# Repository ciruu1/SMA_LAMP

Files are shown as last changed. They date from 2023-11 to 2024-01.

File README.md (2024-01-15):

# SMA_LAMP

This repository contains the source code, hardware design, and documentation for an embedded systems project.

## Directory Structure

### 1. DOCS

- **Description:** This directory holds documentation related to the project.

  - **SysML:** This subdirectory contains System Modeling Language (SysML) diagrams and documentation describing the system architecture and design.

### 2. HW

- **Description:** The hardware-related files and designs are stored in this directory.

  - **SE_ejemplo:** This subdirectory includes hardware design files and documentation for the KiCad design related to the embedded systems project.

### 3. SW

- **Description:** The software source code for the embedded systems project is organized within this directory.

  - **SMA_LAMP.X:** This subdirectory holds the source code for the main module related to lamp control (MPLAB X project).

  - **Terminal:** This subdirectory contains the source code for the terminal module, which may be responsible for user interface and interaction.

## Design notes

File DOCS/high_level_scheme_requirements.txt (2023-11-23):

EM(estructura mecánica)[1]
CA(Circuito de acondicionamiento)[1]
↑
Interfaz HW(Pines)[1]
↓
SMA_LAMP(Sistema de monitorización y actuación):
    - Encendido:
        · leer_configuracion()
        · avisar_SMA_COMP()
    - Apagado:
        · guardar_configuración()
        · avisar_SMA_COMP()
    - Monitorización:
        · recibir_comandos_pc()
        · leer_sensores():
            # Ruido
            # CO2
            # Temperatura
            # Humedad
            # Luminosidad
    - Actuación:
        · enviar_info_pc()
        · modificar_velocidad()
        · modificar_LEDs()

↕
Interfaz_PC(USART)
↕
SMA_COMP(LINUX):
    - SW:
        · enviar_comandos() {cambiar_luz, cambiar_iluminación, modificar_velocidad}
        · mostrar_estado_variables() {Ruido, CO2, Humedad, Temperatura, Luminosidad} [2]
        · comprobar_estado_SMA_LAMP()

[1]: Nos viene ya hecho, no tenemos que desarrollar nada
[2]: Se muestra el estado de los sensores, aquellos que no estén disponibles también aparecerá el estado: NO DISPONIBLE TODAVÍA(De acuerdo con el requisito ENC-20)

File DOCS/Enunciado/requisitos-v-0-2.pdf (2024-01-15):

# Requisitos para lámpara de mesa diseñada para el estudio Sección: Sistema de monitorización y actuación

# LMDE-MA v-0.2

Norberto Cañas

## 1. Introducción

### 1.1. Propósito

Este documento establece un punto de partida, relativamente preciso, para el desarrollo del primer prototipo de un sistema empotrado (SE) para una lámpara de mesa diseñada para el estudio (LMDE). El dispositivo tiene funciones añadidas de monitorización del ambiente cercano, así como funciones de ajuste de la iluminación suministrada y velocidad de giro de un ventilador acoplado a la base del dispositivo.

### 1.2. Alcance

El prototipo a desarrollar se ha dividido en tres componentes.

Estructura mecánica (EM) Suministra los soportes necesarios para alojar el resto de componentes.

Circuito de acondicionamiento (CA) Realiza actividades de acondicionamiento de señal para sensores y actuadores.

Sistema de monitorización y actuación (SMA) Realiza la monitorización de algunas variables ambientales de interés en actividades de estudio, así como suministra la posibilidad de actuar sobre la velocidad de giro de un ventilador, ajustar el color de la luz emitida por la lámpara y la iluminancia de la misma.

Los componentes EM y CA ya disponen de un primer prototipo completamente construido. El presente documento describe qué debe hacer el componente SMA.

1

## 2. Descripción general

### 2.1. Visión general del documento

Se describen a continuación los detalles del sistema que debe construirse.

Este apartado está estructurado de la siguiente forma:

Perspectiva del producto.
Interfaces hardware existentes
Funciones del sistema.
Restricciones.

En el capítulo siguiente (3) se detallan los requisitos específicos.

### 2.2. Perspectiva del producto

El componente SMA debe interactuar con el componente CA, respetando el interfaz de este último. El componente SMA también debe interactuar con un computador personal, en el que realmente se despliega el interfaz que se ofrece al usuario final.

### 2.3. Interfaces hardware existentes

### 2.3.1. Interfaz del componente CA

El componente CA ofrece un interfaz hardware con un conector de pines (cuadrado de 0.64mm de lado, con separación 2.54 mm entre centros) que permite acceder a las siguientes señales (ordenadas según el número de pin), interpretando el sentido de la información según el punto de vista del componente SMA:

1. Nivel de ruido. Señal de entrada analógica que codifica el nivel de ruido en el ambiente circundante.
2. SCL. Línea de sincronización para dispositivos conectados a un bus I2C.
3. SDA. Línea de datos para dispositivos conectados a un bus I2C (el componente SMA actúa como maestro del bus I2C).
4. Humedad relativa. Señal de entrada analógica que codifica la humedad relativa del ambiente circundante.
5. Temperatura. Señal de entrada analógica que codifica la temperatura del ambiente circundante.
6. PWM ventilador. Señal de salida que comanda, con su ciclo de trabajo, el nivel de alimentación del motor DC de un ventilador.
7. SCK (Serial Clock). Línea de reloj de un bus SPI.
8. SDO (Serial Data Out). Linea de salida de datos hacia un bus SPI.

2

El nivel de ruido es una señal analógica cuyos detalles de interpretación se detallan en el apartado de requisitos específicos.

El bus I2C conecta el sensor de luminosidad y el sensor de CO2, y debe funcionar a la velocidad estándard de 100 KHz.

El bus SPI conecta una tira de leds (de adafruit), constituida por leds SK9822.

Los sensores de temperatura y humedad relativa suministran señales analógicas.

Los sensores usilizados (salvo el sensor de nivel de ruido) son los siguientes y deben consultarse sus respectivas hojas técnicas (que acompañan a este documento) para entender como interactuar con ellos.

Sensor de luminosidad VEML7700

Sensor de CO2 iAQ-Core

Sensor de humedad relativa HIH4000

Sensor de temperatura LM35-LP

### 2.3.2. Interfaz computador personal

Para ganar en flexibilidad se ha decidido que el interfaz de monitorización y ajuste de la unidad LMDE, que se ofrezca al usuario final, se despliegue en un computador personal ubicado en la misma mesa de estudio que la lámpara.

El SMA deberá ofrecer un interfaz UART para conectarse con el computador personal, el cual ofrecerá un interfaz USB. Para ello se utilizará el conversor TTL-232R-RPi (FTDI).

### 2.3.3. Interfaz de usuario

El interfaz de usuario debe desarrollarse para una máquina LINUX. A nivel de prototipo existen actualmente los servicios que permiten operar el sistema en linea de comandos (aunque no se respetan todos los requisitos del sistema). Sin embargo, el interfaz definitivo debería ser un interfaz de ventanas.

En cualquier caso, el sistema debe mostrar en pantalla el estado de las variables ambientales (nivel de ruido, nivel de CO2, humedad relativa, temperatura y luminosidad), al tiempo que debe permitir cambiar el color de la luz emitida y el nivel de iluminación, así como la velocidad del ventilador.

Detalles más concretos se indican en el apartado de requisitos específicos.

### 2.4. Funciones del sistema

Las funciones del sistema son fundamentalmente dos:

3

Monitorización El sistema debe monitorizar una serie de parámetros ambientales que tienen interés para determinar si el ambiente de estudio es adecuado. Fundamentalmente son: Nivel de ruido ambiente, nivel de CO2, nivel de temperatura, nivel de humedad relativa, nivel de luminosidad.

Ajuste del comportamiento El sistema debe permitir ajustar el color de la luz emitida de la lámpara, la iluminancia de la luz emitida y la velocidad de rotación de un ventilador sujeto al soporte de la lámpara.

### 2.5. Restricciones

1. Por la configuración seleccionada para el interfaz de usuario, el componente SMA se dividirá en dos subcomponentes.

SMA-LAMP Estará constituido por el el hardware y software ubicado en la lámpara destinado a recibir la información de los sensores, tratar dicha información y enviarla al computador de sobremesa. Del mismo modo atenderá los comandos que lleguen desde el computador de sobremesa para actualizar el comportamiento de los leds así como el del ventilador.

SMA-COMP Será un componente software desplegado en el computador de sobremesa, que ofrecerá el interfaz de la lámpara con el usurio.

2. Por condicionantes externos, el microcontrolador a utilizar en el componente SMA-LAMP debe ser el PIC16F886.
3. Las dimensiones de la placa del componente SMA no pueden ser superiores a 6 cm x 6 cm.
4. Es necesario reservar espacio en la placa para cuatro tornillos de sujeción, de 4mm de diámetro, cerca de las esquinas de la misma. El margen necesario debe ser de 5mm de diámetro para poder alojar la cabeza de los tornillos.

## 3. Requisitos específicos

Encendido del sistema Este caso de actividad contempla las acciones que deben realizarse al encender el sistema.

ENC-10 Por defecto, se arrancará en primer lugar SMA-LAMP, alimentando la lámpara, para a continuación arrancar SMA-COMP, en el computador de sobremesa.

ENC-20 En el momento de arrancar se ofrecerá la información de los sensores disponibles y se indicará el estado de aquellos que requieran un proceso arranque más prolongado.

ENC-30 La lámpara debe arrancar respetando la última configuración utilizada en lo referente a leds y ventiladores. En el caso de ser la primera vez que se enciende se optará por una opción intermedia de luz blanca y ventilador apagado.

Apagado del sistema Este caso de actividad contempla las acciones que deben realizarse ante los diferentes escenarios de apagado del sistema.

AP-10 Si se apaga el sistema SMA-COMP, el sistema SMA-LAMP debe seguir funcionando con normalidad según la última configuracion establecida.

4

AP-20 Si se apaga SMA-LAMP, SMA-COMP debe indicar que SMA-LAMP se ha desconectado. En este caso, SMA-COMP no debe volver a operar hasta despues de que la aplicación se haya reinicializado.
AP-30 SMA-COMP debe ofrecer alguna alternativa para apagar la aplicación.

Monitorización de variables ambientales Este caso de actividad contempla las acciones que deben realizarse en relación con la monitorización de variables ambientalers.

MO-10 El nivel de ruido es una señal en voltaje. Deben considerarse las siguientes categorías para el ruido:
Ruido bajo La lectura del convertidor analógico digital está en el intervalo [0,400].
Ruido intermedio La lectura del convertidor analógico digital está en el intervalor [401, 900].
Ruido alto La lectura del convertidor analógico digital está por encima de 900.

MO-20 El nivel de ruido debe monitorizarse cada 10 ms, pero en el interfaz humano solo debe mostrarse la catergoría de ruido más alta alcanzada cada segundo.

MO-30 El nivel de CO2, humedad relativa, temperatura y la iluminancia, deben ser muestreados cada 5 segundos y actualizarse en pantalla con el mismo periodo.
MO-40 La unidades a utilizar para las magnitudes muestreadas (salvo el ruido, que ya ha sido categorizado) deben ser:

PPM (partes por millon) para el nivel de CO2.
% (tanto por ciento) para la humedad relativa. ºC (grados centígrados) para la temperatura. lx (Lux) para la iluminancia.

Ajuste de actuadores Este caso de actividad contempla las acciones a tomar relacionados con el comportamiento de los LEDs y el ventilador.

AC-10 SMA-COMP debe ofrecer al usuario la posibilidad de cambiar el comportamiento de los LEDs. Para ellos debe suministrar la posibilidad de especificar el color con un código RGB, en el que se permita un valor entre 0 y 255 para cada color. Al mismo tiempo debe permitir codificar el nivel de iluminación con un código que pueda tomar valores entre 0 y 31.

AC-29 SMA-COMP debe ofrecer al usuario la posibilidad de cambiar la velocidad del ventilador. Dicha velocidad se codifica en tanto por ciento con valores posibles entre 0 % y 100 %.

## 4. Comentarios finales

Aunque no se esperan cambios de gran envergadura en este documento, su estado debe calificarse como inestable, por existir todavía la posibilidad de sufrir pequeñas modificaciones.

5

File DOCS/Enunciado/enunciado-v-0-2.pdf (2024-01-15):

# Proyecto a realizar por los alumnos de Sistemas Empotrados

v-0.2

Norberto Cañas de Paz

## 1. Introducción

Los alumnos de Sistemas Empotrados deben realizar el siguiente proyecto, durante el periodo docente. Con él se pretende asentar conocimientos y destrezas en el marco de un desarrollo real, de complejidad adaptada a los objetivos de la asignatura.

## 2. Objetivo

Construir un prototipo de sistema empotrado (SE) que debe permitir operar una lámpara de estudio que dispondrá de funciones añadidas de monitorización del ambiente de trabajo.

Los objetivos generales son los siguientes:

1. Monitorizar un conjunto de parámetros ambientales de interés, ya establecidos, del espacio de estudio.
2. Permitir ajustar la forma de operar de algunos elementos actuadores disponibles.

### 2.1. Componentes destacados del prototipo

El prototipo actualmente en desarrollo se ha dividido en tres componentes estructurales:

1. Soporte mecánico de los diferentes dispositivos del sistema.
2. Circuito de acondicionamiento de señales analógicas.
3. Sistema programable encargado de interactuar con sensores, actuadores, así como suministrará interfaces de usuario.

En este momento del proyecto, ya se han planteado y construido prototipos del componente mecánico y el componente de acondicionamiento electrónico. Es necesario abordar el desarrollo del primer prototipo del sistema programable.

1

### 2.2. Trabajo a realizar

El trabajo a realizar se descompone en los siguientes hitos:

Especificación Especificación del sistema completo (HW + SW)

1. Se suministrará a los alumnos un documento de especificación del proyecto, que deberán aclarar y completar en una sesión con el profesorado de la asignatura.
2. A partir del análisis de la especificación debe plantearse un plan de trabajo, con una estimación del esfuerzo necesario y una planificación temporal, atendiendo a la configuración del equipo de desarrollo.
3. A partir del análisis de la especificación, debe prepararse un presupuesto estimado del desarrollo del proyecto, incluyendo material y coste del trabajo de ingeniería de los participantes.

Diseño A partir de la documentación generada en el apartado anterior, los alumnos deberán preparar un documento de diseño hardware y software del SE.

1. Diseño software de alto nivel. Se planteará el diseño software de alto nivel (solo grandes bloques del sistema) utilizando para ello un diagrama de bloques (SysML).
2. Diseño lógico hardware. Debe elaborarse el diseño lógico hardware (o diseño esquemático) necesario para atender los requisitos planteados para el sistema (ver herramientas obligatorias).
3. Diseño software detallado. Por medio de diagramas de estado, diagramas de secuencia u otros recursos que se consideren apropiados, debe plantearse el diseño detallado del componente software del sistema.
4. Diseño físico hardware. A partir de la utilización de alguna herramienta de diseño, debe obtenerse el diseño físico hardware, respetando para ello el diseño lógico hardware previamente planteado (ver herramientas obligatorias).
5. En el apartado de diseño deben plantearse las siguientes trazas:
a) Traza de componentes del diseño software de alto nivel contra requisitos.
b) Traza de diseño físico (HW) contra diseño lógico (HW) haciendo las siguientes comprobaciones:
1) Todos los componentes del diseño lógico aparecen en el diseño físico.
2) Todas las conexiones establecidas en el diseño lógico aparecen en el diseño físico.
c) Comprobaciones añadidas del diseño físico (HW).
1) No hay soldaduras con imposibilidad de ser realizadas.
2) El espacio reservado para el conector de programación permite insertar la sonda sin chocar con ningún componente (Pickit3 o Pickit4 según indicaciones del profesorado).
3) Las lineas de conexión entre componentes tienen el ancho adecuado y separación suficiente para el proceso de fabricación a utilizar.
4) Todos los componentes están correctamente alimentados.
5) Se han introducido marcas de serigrafiado adecuadas para identificar correctamente el circuito y su interfaz.
6) Se incluyen las marcas para el mecanizado de sujeción. Por defecto taladros de métrica 4.
7) No hay pistas que hagan contacto con las partes metálicas del mecanizado de sujeción.

2

Construcción. A partir de los diseños planteados, en esta etapa deben construirse los circuitos y programas que configuren el SE.

Pruebas. Las pruebas a realizar deben respetar las siguientes consideraciones.

1. En paralelo con las actividades de la etapa de diseño del SE, debe plantearse el protocolo de pruebas a realizar, tanto a los componentes hardware del SE como a sus componentes software.
2. El resultado de las pruebas debe quedar registrado en un documento (que posteriormente se detalla en este enunciado).

## 3. Entregas a realizar

Especificación y diseño. Debe incluirse en el documento todos los elementos indicados en el plan de trabajo (especificación y diseño), comentando de forma detallada los diagramas incluidos. Además deben incorporarse los siguientes apartados.

1. Cuadro de tiempos invertidos, en cada tarea o labor, por trabajo individual de los participantes y por trabajo en grupo.
2. Desviación del tiempo invertido en las actividades de diseño con respecto al planificado en el periodo de especificación.

Construcción y pruebas. El informe debe tener, al menos, los siguientes apartados.

1. Incidencias (y solución en el caso de ser necesario) en la construcción del componente HW del SE.
2. Incidencias (y solución en el caso de ser necesario) en la programación del componente SW del sistema empotrado.
3. Descripción del protocolo de pruebas.
4. Listado de pruebas que han tenido éxito junto con la descripción de los defectos que producían el fallo, alternativas de solución (si se ha considerado más de una) y solución seleccionada.
5. Cuadro de tiempos invertidos, en cada tarea o labor, por trabajo individual de los participantes y por trabajo en grupo.
6. Desviación del tiempo invertido con respecto al planteado.

## 4. Evaluación

La nota obtenida en el desarrollo del proyecto contribuye en un 30 % a la nota final de la asignatura.

1. La primer entrega (especificación y diseño) contribuye en un 20 % sobre la nota final de la asignatura.
2. La segunda entrega (construcción y pruebas) contribuye en un 10 % en la nota final de la asignatura.

Además de la documentación escrita, el profesorado de la materia se reserva la posibilidad de solicitar a los alumnos explicaciones añadidas para verificar aspectos relacionados con el desarrollo del trabajo.

3

## 5. Herramientas

En este apartado se enumeran las herramientas que es obligatorio utilizar, así como aquellas que tienen un caracter optativo.

Herramientas obligatorias. Herramientas cuya utilizacion es indiscutiblemente obligatoria para alguna de las actividades de desarrollo del proyecto.

1. Kicad. Herramienta de libre distribución para el diseño y obtención de ficheros de fabricación de circuitos.
2. MPLAB X. Herramienta de programación y simulación de los microcontroladores de la casa Microchip.
3. xc8. Compilador de C para los microcontroladores de gama media de la casa Microchip.

Herramienta optativa. Herramienta cuya utilización es muy recomendable, pero no obligatoria, para alguna de las actividades del desarrollo del proyecto.

1. Eclipse y Papyrus. Herramienta para generar diseños gráficos (UML y SysML) de nuestros sistemas software.

Todas estas herramientas estarán a disposicion de los alumnos en los ordenadores de los laboratorios en los que se desarrollen las prácticas.

## Apéndice A. Documentación de apoyo

La documentación de apoyo para el desarrollo de este proyecto será publicada junto con este enunciado.

4

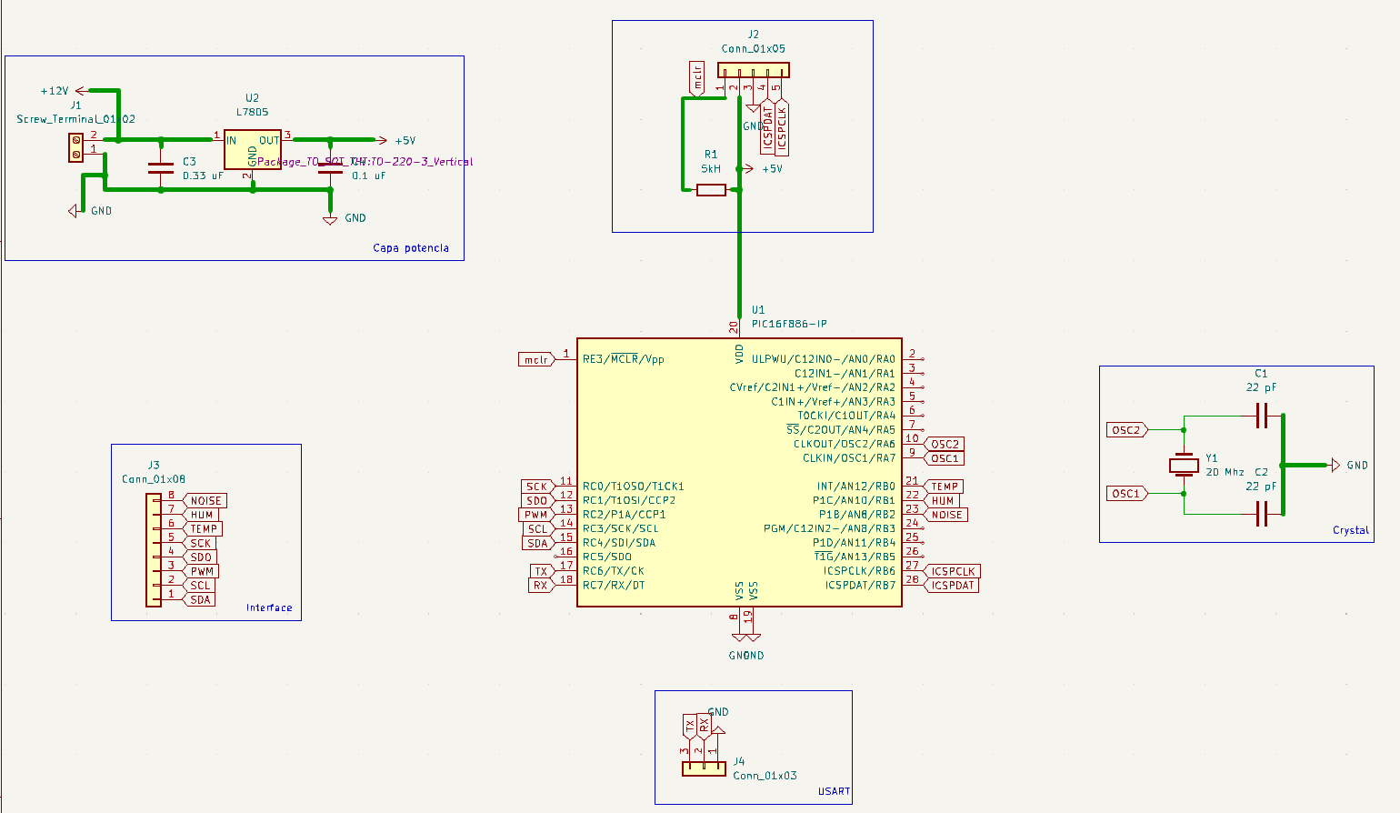
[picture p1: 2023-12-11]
DOCS/SysML/SE_LAMP/image.png

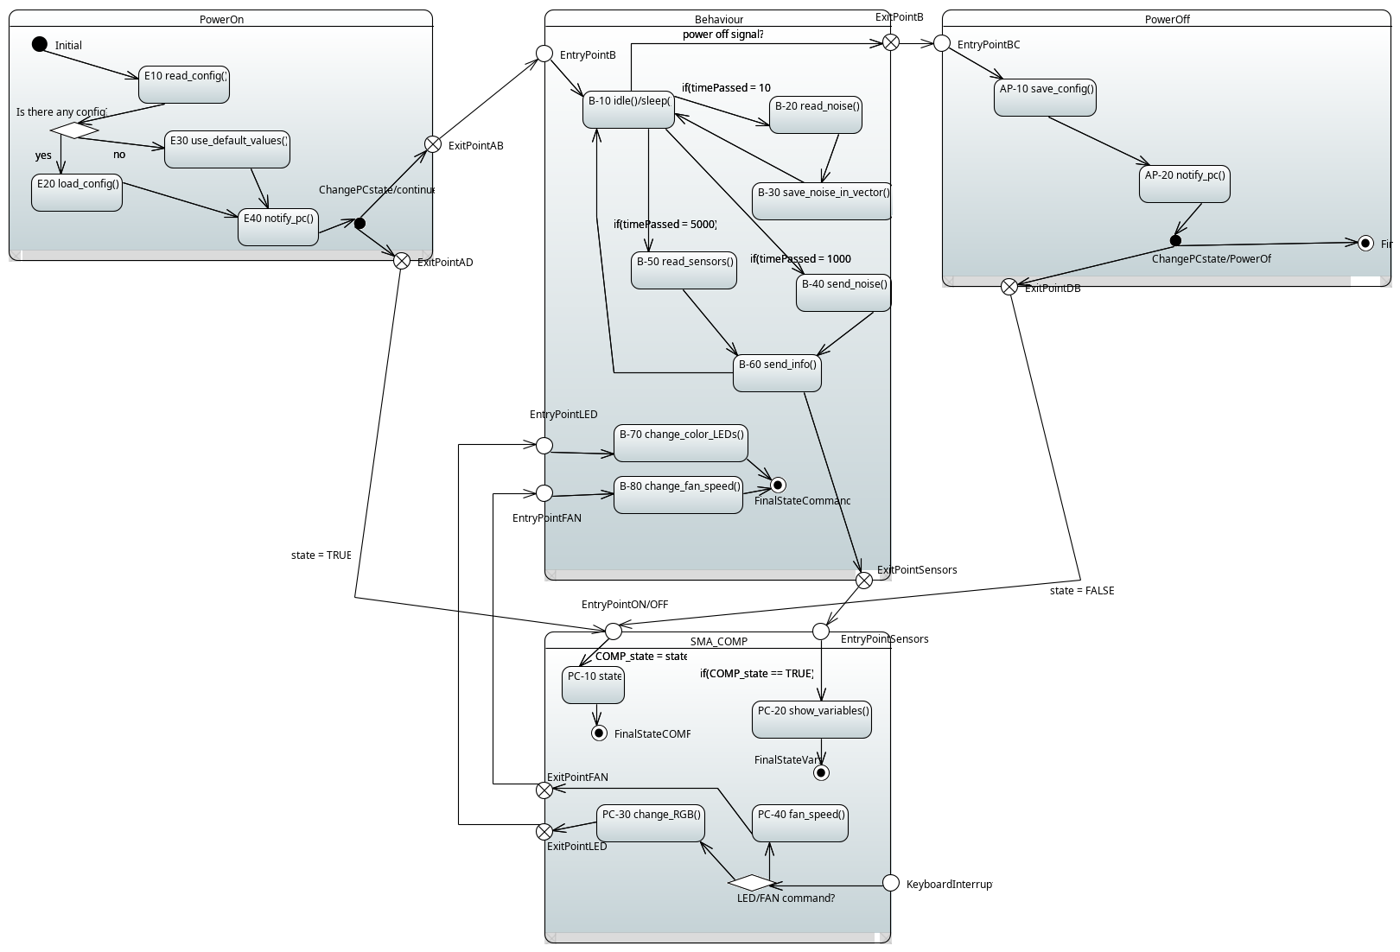
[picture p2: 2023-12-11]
DOCS/SysML/SE_LAMP/State_Diagram.PNG

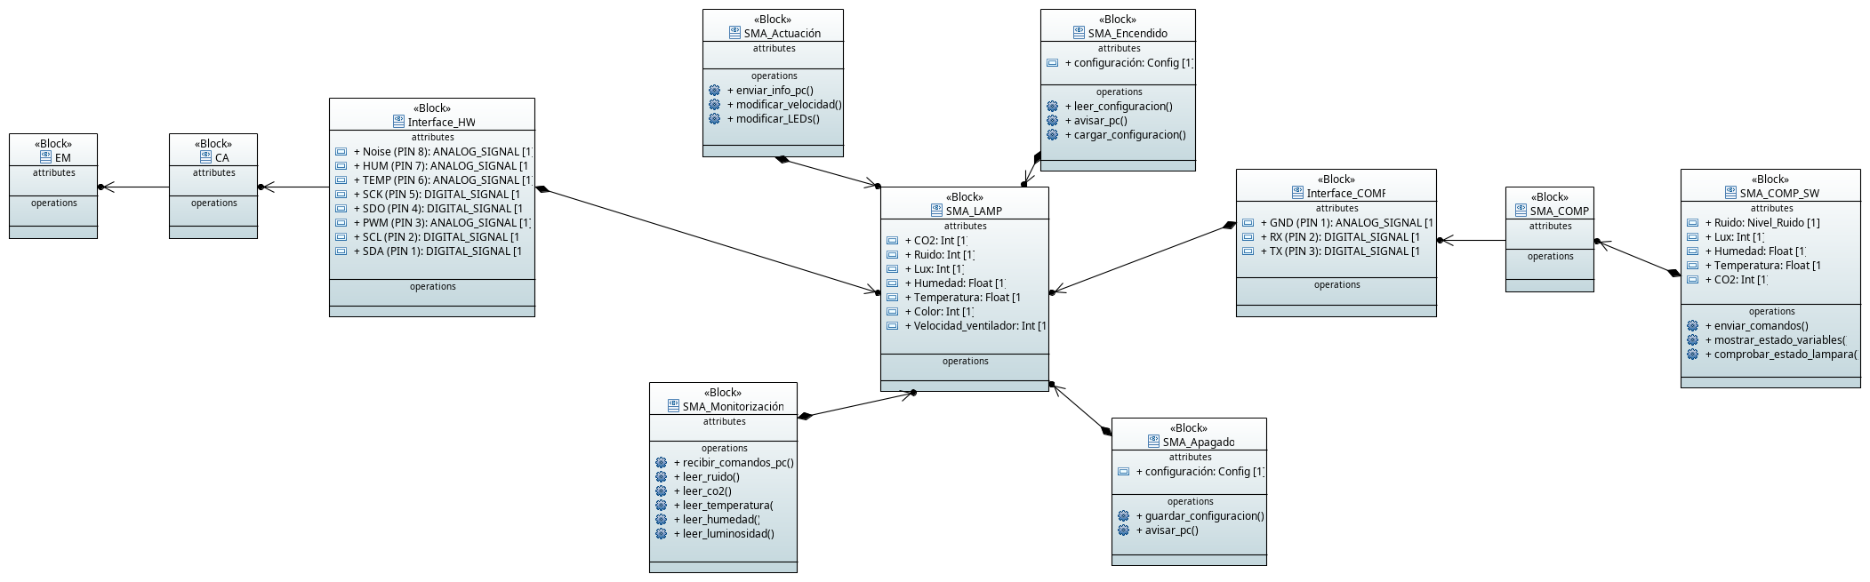
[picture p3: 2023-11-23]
DOCS/SysML/SE_LAMP/High_Level_Diagram.PNG

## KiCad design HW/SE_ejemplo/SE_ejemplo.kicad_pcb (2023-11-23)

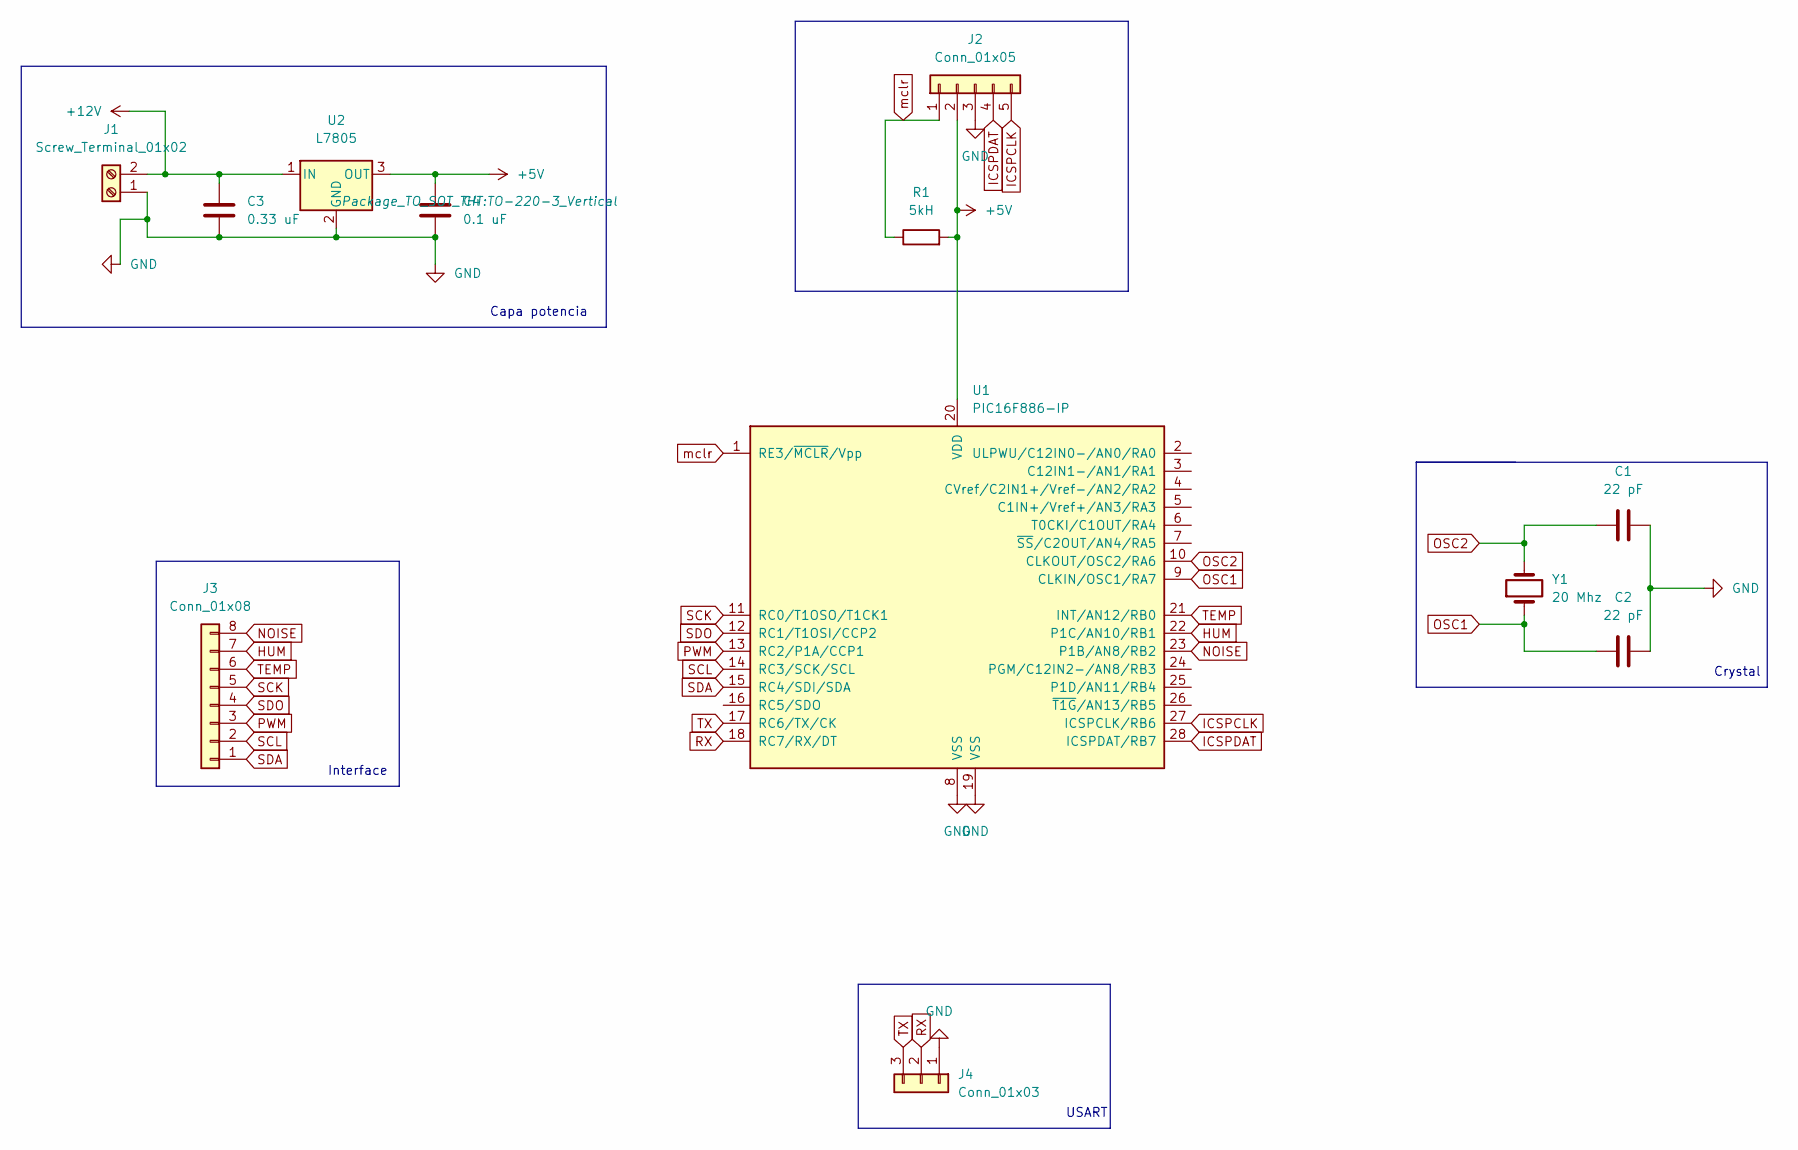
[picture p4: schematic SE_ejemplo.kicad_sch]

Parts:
C1, C2: 22 pF; C_Disc_D3.8mm_W2.6mm_P2.50mm
C3: 0.33 uF; CP_Radial_D5.0mm_P2.50mm
C4: 0.1 uF; CP_Radial_D5.0mm_P2.50mm
J1: Screw_Terminal_01x02; TerminalBlock_Phoenix_MKDS-1,5-2-5.08_1x02_P5.08mm_Horizont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
J2: Conn_01x05; PinSocket_1x05_P2.54mm_Vertical
J3: Conn_01x08; PinSocket_1x08_P2.54mm_Vertical
J4: Conn_01x03; PinSocket_1x03_P2.54mm_Vertical
R1: 5kH; R_Axial_DIN0204_L3.6mm_D1.6mm_P5.08mm_Horizontal
U1: PIC16F886-IP; DIP-28_W7.62mm
U2: L7805; TO-220-3_Vertical
Y1: 20 Mhz; Crystal_HC18-U_Vertical

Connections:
+5V: C4.1, J2.2, R1.2, U1.20 (VDD), U2.3 (OUT)
+12V: C3.1, J1.2, U2.1 (IN)
GND: C1.1, C2.1, C3.2, C4.2, J1.1, J2.3, J4.1, U1.8 (VSS), U1.19 (VSS), U2.2 (GND)
HUM: J3.7, U1.22 (P1C/AN10/RB1)
ICSPCLK: J2.5, U1.27 (ICSPCLK/RB6)
ICSPDAT: J2.4, U1.28 (ICSPDAT/RB7)
NOISE: J3.8, U1.23 (P1B/AN8/RB2)
OSC1: C2.2, U1.9 (CLKIN/OSC1/RA7), Y1.1
OSC2: C1.2, U1.10 (CLKOUT/OSC2/RA6), Y1.2
PWM: J3.3, U1.13 (RC2/P1A/CCP1)
RX: J4.2, U1.18 (RC7/RX/DT)
SCK: J3.5, U1.11 (RC0/T1OSO/T1CK1)
SCL: J3.2, U1.14 (RC3/SCK/SCL)
SDA: J3.1, U1.15 (RC4/SDI/SDA)
SDO: J3.4, U1.12 (RC1/T1OSI/CCP2)
TEMP: J3.6, U1.21 (INT/AN12/RB0)
TX: J4.3, U1.17 (RC6/TX/CK)
mclr: J2.1, R1.1, U1.1 (RE3/~MCLR/Vpp)

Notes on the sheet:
Capa potencia
Interface
Crystal
USART

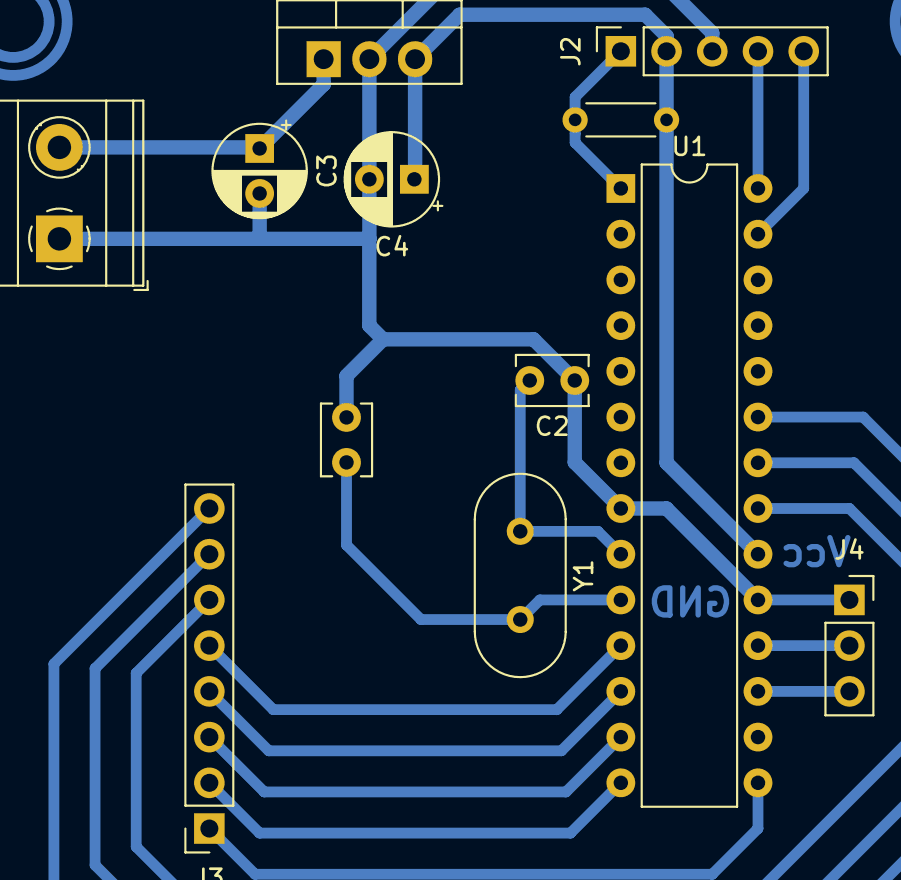
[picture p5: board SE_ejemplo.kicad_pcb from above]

Board: 2 copper layers, 12 parts (0 on the bottom side), 18 nets.

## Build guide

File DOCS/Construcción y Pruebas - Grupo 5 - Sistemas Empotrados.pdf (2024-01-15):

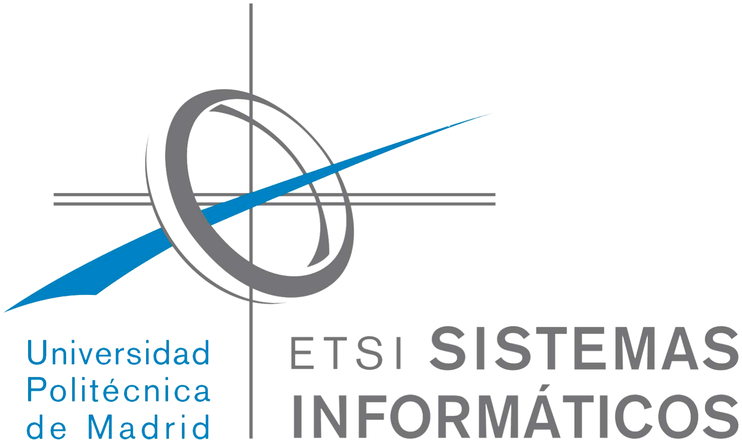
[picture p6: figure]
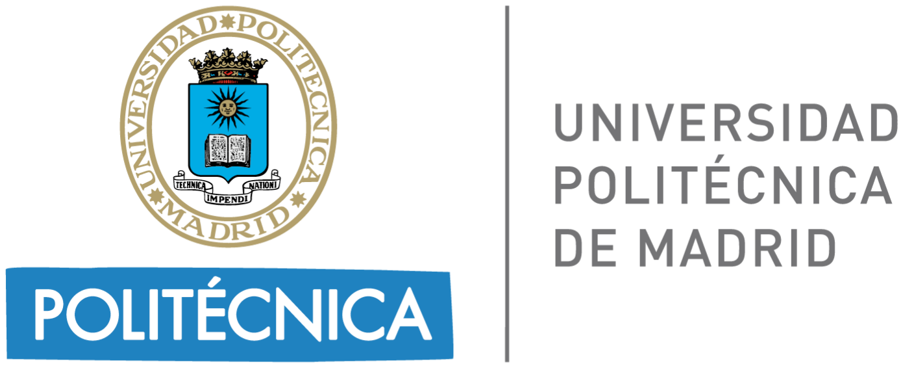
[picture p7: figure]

# Sistemas Empotrados

# Construcción y Pruebas

# Grupo 5

Javier Cirugeda Bugallo

Santiago Ágreda Jiménez

Pablo Hidalgo Gamo

Iván García Salgado

# Índice

Sistemas Empotrados - Grupo 5

## Introducción

Este informe se centra en las incidencias y desafíos encontrados, enfocándose principalmente en los dos bloques fundamentales de desarrollo que se planificaron: Hardware y Software. El objetivo principal es proporcionar una visión detallada de las complejidades encontradas durante la construcción de estos bloques esenciales.

En la sección inicial, se detallan las incidencias surgidas en el ámbito del hardware, abordando cuestiones técnicas y cualquier irregularidad identificada durante la implementación de esta parte crucial del proyecto. Asimismo, se examinan las incidencias relacionadas con el software, explorando temas como compatibilidad, integración de módulos y posibles errores de código.

Una parte significativa de este informe se dedica a la resolución de estas incidencias, donde se destacan las estrategias para superar las incidencias sufridas. Se ofrece una perspectiva sobre las decisiones tomadas, optimizaciones realizadas y cualquier medida implementada para garantizar el cumplimiento de la planificación.

Posteriormente, el documento concluye con la planificación y diseño de pruebas de validación y verificación del sistema. Aquí, se describen con detalle los protocolos y procedimientos establecidos para evaluar la funcionalidad y robustez tanto del hardware como del software.

En resumen, este informe intenta cumplir su objetivo: asegurar que el producto final cumpla con los estándares de rendimiento esperados y garantizar la calidad y eficacia en todas las etapas del proyecto.

## Incidencias

A continuación se detallan, en dos bloques distinguidos, las incidencias que se encontraron en el desarrollo del sistema, tanto Hardware y Software, respectivamente, así como el porqué sucedieron y la desviación de tiempo que supusieron para nuestra planificación inicial.

- Incidencias desarrollo Hardware

Siguiendo en nuestro esquema de diseño comentado en la anterior entrega, se enumeran las incidencias en la construcción Hardware del proyecto.

[HW] #1. La primera incidencia encontrada fue en el diseño físico del proyecto, donde el pin SCK de I2C coincide con el de datos de SPI.

[HW] #2. Otro de los retos en el diseño Hardware fue el esbozo de las líneas de cobre que cumplieran con las dimensiones físicas de la placa, que esta no podía sobrepasar de los impuestos del modelo fisica donde sería empotrada. Además, la colocación de los distintos periféricos hardware fue vital para que el camino trazado por el cobre no produjera cruces, lo que supondría un corte, y esto el no funcionamiento de la misma.

[HW] #3. En la construcción física, y en los primeros pasos, se eligió de base un retal de silicio defectuoso, lo que conllevo que en dibujo de las líneas de cobre se produjeran microcortes muy difíciles de arreglar con la soldadura a mano, por lo que este proceso se tuvo que repetir hasta en dos ocasiones por motivos similares con distintos resultados. Esta incidencia desvió la finalización de la construcción en dos semanas.

[HW] #4. En el diseño físico en KiCad, no se tuvo en cuenta el tamaño de la Sonda de grabación del PIC16F886, por lo que el regulador de tensión entorpecia la entrada de esta.

- Incidencias desarrollo Software

[SW] #1. La recepción de datos en el protocolo UART por parte del microcontrolador tenía pérdida de datos.

[SW] #2. | El sensor de luminosidad sólo leía valores nulos o máximos.
[SW] #3. | El PWM no generaba señales correctamente.
[SW] #4. | Integración completa del sistema software.

## Resolución de problemas

Se detallan, de las incidencias enumeradas anteriormente, las resolución a las mismas encontradas en las distintas etapas. Se divide en dos bloques siguiendo la planificación de este documento.

- Resolución en Hardware

En la incidencia 1, se resolvió estudiando la configuración de cada pin para encontrar uno de similitud comportamiento y compatibilidad con el nuevo requisito. Para ello se usó los pines 10 y 11 para SCK y SCL, que sí podían ser usados en esos pines, dejando libre su hueco de los pines SCL y SDA, que no tenían compatibilidad con el resto de los pines no utilizados.

La incidencia hardware 2 se resolvió colocando cuidadosamente en la simulación los componentes donde no entorpecieron en el camino de cobre de otros. También se eligieron dimensiones distintas del ancho del cobre distinguiendo entre Datos y Voltaje, 0.6mm y 1mm respectivamente, asegurando que en la producción física no se produjeran cortes en la misma.

Ya en la construcción física de lo diseñado, la incidencia 3, y la primera de esta etapa, se solucionó repitiendo hasta en dos ocasiones el proceso de fabricación de la placa PCB, finalmente se solventó cortando de otro retal más moderno.

Finalmente, en la incidencia hardware 4, se inclinó el regulador de tensión unos 20º, el máximo que nos permite el correcto funcionamiento de la LRU, y la conexión de la sonda de grabación sin ningún problema. Esta modificación física se estudió también que no se interpusiera en los requisitos físicas donde el dispositivo diseñado seria empotrado.

- Resolucion de Software

Incidencia 1: La UART omitía datos que le eran enviados desde la interfaz en el ordenador, descubrimos que cuando leíamos del registro RCREG el tiempo que se tardaba en procesar el dato leído otro era enviado y sobrescribía este registro y eso provocaba la pérdida de datos. Nuestra solución fue implementar un pequeño tiempo de espera de 10ms a la hora de enviar el dato desde el ordenador para que le diera tiempo al microprocesador a procesar el dato leído.

Incidencia 2: En este caso era un problema de configuración, leíamos el dato sin haber configurado el sensor. Lo solucionamos buscando en el datasheet la trama correcta a enviar para leer el sensor y después de eso funcionó correctamente.

Incidencia 3: En este caso fue un descuido por nuestra parte, estaba bien configurado pero no llamábamos a la función de configuración en ningún lado, una vez hecho comprobamos con un osciloscopio que funcionaba correctamente.

Incidencia 4: Una vez comprobados todos los módulos por separado la integración completa del sistema no funcionó a la primera, hubo que modificar algunas instrucciones y cambiar el flujo de algunas interrupciones para que todo funcionara bien.

## Desviación de tiempo

Durante el desarrollo de todos las partes del proyecto tuvimos varias incidencias, mencionadas anteriormente, que nos retrasaron en la consecución de los objetivos en las fechas establecidas.

[HW] #1. | Esta incidencia fue resuelta en un corto plazo, varios minutos.
[HW] #2. | La segunda incidencia hardware se necesitó más tiempo para solucionarlo, con
unas horas bastó.

[HW] #3. Esta fue la incidencia que más tiempo tuvimos que dedicar, necesitamos dos clases extra para definitivamente tener la placa en completas condiciones.

[HW] #4. En la última incidencia de Hardware, no se necesitó mucho tiempo como se explicará en el siguiente apartado.

[SW] #1. Llevó como unas 4 horas poder resolver este incidente, ya que al principio no sabíamos lo que estaba pasando, hasta que probamos a aplicar el tiempo de espera y todo funcionó.

[SW] #2. Estuvimos como unos 30 minutos leyendo la documentación del sensor hasta que encontramos la secuencia correcta de configuración.

[SW] #3. Hasta que nos dimos cuenta que no estábamos llamando a la función pudimos haber perdido unas 2 horas perfectamente.

[SW] #4. Es lo que más tiempo ha llevado de todo, ya que es la prueba definitiva, pero en 2 días de clase se solucionó, unas 10 horas en total perfectamente.

## Protocolo de pruebas

Durante el desarrollo del proyecto se realizaron una serie de pruebas Hardware y Software que validaron y verificaron el correcto funcionamiento del sistema y/o la implementación de los requisitos del proyecto.

Estas pruebas se pueden dividir en dos sub bloques de pruebas, unitarias y colectivas, donde la principal diferencia radica en el componente a verificar. Las unitarias se realizaron durante el desarrollo, paralelamente a las pruebas Hardware, donde se iban comprobando que los componentes Software:

1) Funcionamiento
2) Resultado esperado
3) Cumplian con el requisito especificado en el proyecto

Una vez que se iban agrupando funcionalidades se fueron realizando la otra parte de pruebas: Colectivas, donde se realizaban un conjunto de pruebas que comprobaban que el componente cumplían con las especificaciones.

A continuación, se detallan las pruebas realizadas, tanto Unitaria y Colectiva, respectivamente.

- Pruebas unitarias
- En USART, se codificaron dos funciones: envío y recepción. Además, se desarrolló una interfaz de software en el ordenador maestro y se probó el envío y la recepción del mismo dato a través de USART, utilizando Minicom.
- En PWM, se validó la señal generada con la configuración del microcontrolador mediante un osciloscopio. Si este mostraba el ciclo de reloj y el comportamiento esperado para el controlador de la señal del ventilador, se considera exitosa la prueba.

- En ADC, se realizaron mediciones con el multímetro para observar el intervalo de voltaje recibido. Se verificó que éste correspondiera con el valor generado por el convertidor analógico-digital.
- En SPI, se leyó la documentación hasta que llegamos a la secuencia correcta de ejecución, hasta que el componente hardware a verificar (tira LEDs) actuó de acuerdo con las instrucciones enviadas.
- En I2C, se verificó que el comando de configuración se enviará correctamente, ya que era crucial para el correcto funcionamiento. En esta fase, nos apoyamos en la UART para recibir la confirmación de que el comando de configuración era el esperado.
- Pruebas colectivas
- Flujo de comportamiento, se hicieron pruebas en cada inserción de componente que el flujo de comportamiento del resto de los componentes Hardware no se veía afectado con las nuevas modificaciones.
- Memoria EEPROM, una vez que los componentes cumplían con los especificados, se probó que las funciones de escritura y lectura de memoria guardaba los valores correctos para su posterior puesta en marcha.
- Interfaz gráfica, comunicación ordenador-microcontrolador, una vez programada la interfaz gráfica, se comprobó que la información mandada a través del ordenador era la esperada, y que el comportamiento de los periféricos cumplía con lo especificado.

## Conclusión

En conclusión, las incidencias que surgieron durante el desarrollo del proyecto eran esperadas, dentro de unos márgenes, en la planificación, minimizando así las desviaciones en los plazos establecidos. Las soluciones implementadas no solo sirvieron para superar errores, sino que también contribuyeron significativamente a la mejora tanto del producto final como de los conocimientos extraídos a lo largo del proceso de desarrollo.

El equipo ha conseguido en todo momento anteponerse a las adversidades, incluso las ajenas a nosotros, nunca decayendo en motivación y esfuerzo, señal de la robustez del sistema, su desarrollo y las pruebas.

## Anexo

Se adjunta además el repositorio Github donde se encuentran todos los documentos relativos al

desarrollo de la práctica.

Ciruu. (s. f.). GitHub - CIRUu1/SMA_LAMP: An Embedded Systems project.

GitHub. https://github.com/ciruu1/SMA_LAMP

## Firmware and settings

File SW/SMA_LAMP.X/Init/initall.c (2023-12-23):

#include <xc.h>
#include <proc/pic16f886.h>

#define _XTAL_FREQ 20000000

/*
 Configure USART
 */

void init_uart(void)
{
    TXSTAbits.BRGH = 0;
    BAUDCTLbits.BRG16 = 0;

    // SPBRGH:SPBRG =
    SPBRGH = 0;
    SPBRG = 32; // 9600 baud rate with 20MHz Clock

    TXSTAbits.SYNC = 0; /* Asynchronous */
    TXSTAbits.TX9 = 0; /* TX 8 data bit */
    RCSTAbits.RX9 = 0; /* RX 8 data bit */

    PIE1bits.TXIE = 0; /* Disable TX interrupt */
    PIE1bits.RCIE = 1; /* Enable RX interrupt */

    RCSTAbits.SPEN = 1; /* Serial port enable */

    TXSTAbits.TXEN = 0; /* Reset transmitter */
    TXSTAbits.TXEN = 1; /* Enable transmitter */

    RCSTAbits.CREN = 1; // Habilita la recepción continua

}

void init_adc(void)
{
    ADCON0bits.ADCS1 = 1;
    ADCON0bits.ADCS0 = 0;
    ADCON0bits.CHS = 0b1100;
    ADCON0bits.GO = 0;
    ADCON0bits.ADON = 1;
    ADCON1bits.ADFM = 1;
    PIE1bits.ADIE = 1; // Activa la interrupcion en el ADC

    ADCON1bits.VCFG1 = 0;
    ADCON1bits.VCFG0 = 0;
    TRISBbits.TRISB0 = 1;
    ANSELHbits.ANS12 = 1;

}

void init_timer0()
{
    OPTION_REGbits.T0CS = 0;
    OPTION_REGbits.PSA = 0;
    OPTION_REGbits.PS = 0b111; // Fosc/32
    INTCONbits.T0IE = 1; // Habilita las interrupciones del timer0
    INTCONbits.T0IF = 0;

    TMR0 = 159; // Cada 5 mseg   256-97  (5*10^6/ 256)*0.005 = 97.6 
}

void init_timer2(void) {
    T2CON = 0;
    T2CONbits.TOUTPS = 0b0000;
    T2CONbits.TMR2ON = 1;
    T2CONbits.T2CKPS = 0b00;
 
    PIE1bits.TMR2IE = 1;


}

void init_pwm(void) {
    CCP1CONbits.P1M = 0b00; // Salida única; P1A modulado; P1B, P1C, P1D asignados como pines de puerto
    CCP1CONbits.DC1B = 0b11; // Modo PWM
    CCP1CONbits.CCP1M = 0b1100; // Modo PWM; P1A, P1C activos en alto; P1B, P1D activos en alto
    CCPR1L = 0; // El trabajo comienza en 0 %
    PR2 = 167; // Para que el periodo del PWM sea 30Khz o 0.033 ms
    TRISC2 = 0; // Puerto C configurado como salida
}

void init_I2C()
{
    // Configuración del módulo I2C
    SSPCON = 0b00101000; // Habilitar el modo I2C Master, velocidad estándar (100kHz)
    SSPADD = ((_XTAL_FREQ / 4) / 100000) - 1; // Calcular el valor del registro de divisor para 100kHz
    SSPSTAT = 0;
    
    TRISC3 = 1;  // Configurar el pin RC3 como entrada para SDA
    TRISC4 = 1;  // Configurar el pin RC4 como entrada para SCL
}

void init_SPI() {
    //TRISC0 = 0; // SCK como salida (reloj)
    //TRISC1 = 0; // SDO como salida (Maestro manda esclavo)
    TRISCbits.TRISC0 = 0;
    TRISCbits.TRISC1 = 0;
    TRISAbits.TRISA5 = 1;
}

void init(void)
{
    OSCCON = 0b00001000;
    INTCONbits.GIE = 1;
    //INTCONbits.PEIE = 1;
    init_timer0();
    init_timer2();
    init_pwm();
    init_uart();
    init_adc();
    init_I2C();
    init_SPI();
}

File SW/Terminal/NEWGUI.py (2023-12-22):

import re
import serial
import customtkinter as ctk
from CTkColorPicker import *
from serial.serialutil import SerialException
from time import sleep

# Default values
color = "#ffffff"
intensity = 255
speed = 0
red = 0xFF
green = 0xFF
blue = 0xFF
'''
port_enabled = True


ser = serial.Serial()
port_enabled = False


def config_serial():
    global ser
    ser = serial.Serial(
        port="/dev/ttyUSB0",
        baudrate=9600,
        bytesize=serial.EIGHTBITS,
        parity=serial.PARITY_NONE,
        stopbits=serial.STOPBITS_ONE,
        timeout=1,
        xonxoff=False,
        rtscts=False,
        write_timeout=None,
        dsrdtr=False,
        inter_byte_timeout=None,
        exclusive=None
    )


def retry():
    global ser, port_enabled
    try:
        config_serial()
        port_enabled = True
    except SerialException:
        pass
    finally:
        if port_enabled:
            root.quit()


root = ctk.CTk()
root.geometry("210x100")
root.title("SMA_COMP")
root.resizable(False, False)
ctk.CTkLabel(root, text="SMA_COMP\nNOT AVAILABLE", font=("Arial", 25), text_color='yellow').pack(padx=5, pady=5)
ctk.CTkButton(root, text="Retry", command=retry).pack(padx=5, pady=5)
root.mainloop()
'''

ser = serial.Serial(
        port="/dev/ttyUSB0",
        baudrate=9600,
        bytesize=serial.EIGHTBITS,
        parity=serial.PARITY_NONE,
        stopbits=serial.STOPBITS_ONE,
        timeout=1,
        xonxoff=False,
        rtscts=False,
        write_timeout=None,
        dsrdtr=False,
        inter_byte_timeout=None,
        exclusive=None
    )


def hex_to_rgba(color_hex):
    global red, green, blue
    # Eliminar el carácter '#' si está presente
    if color_hex.startswith('#'):
        color_hex = color_hex[1:]

    # Convertir el código hexadecimal a valores decimales
    color_dec = int(color_hex, 16)

    # Obtener los componentes RGB y A
    red = (color_dec >> 16) & 255
    green = (color_dec >> 8) & 255
    blue = color_dec & 255

    # Devolver los valores
    return red, green, blue


def button_update():
    # TODO Enviar aquí la config por la UART
    #print(color)

    #print(intensity)
    t = 0.01
    # LEDs
    # "LRGBI" where 'RGB' is the color and 'I' the intensity of light
    ser.write('R'.encode('utf-8'))
    sleep(t)
    ser.write(red.to_bytes(1))
    sleep(t)
    ser.write(green.to_bytes(1, 'big'))
    sleep(t)
    ser.write(blue.to_bytes(1, 'big'))
    sleep(t)
    ser.write(intensity.to_bytes(1, 'big'))
    sleep(t)
    CCPR1L = int(float(speed / 100) * 167)
    ser.write(CCPR1L.to_bytes(1, 'big'))
    sleep(t)
    ser.write('\r'.encode())

    print(hex_to_rgba(color))
    print(f"{red} {green} {blue} speed: {CCPR1L}")

    #ser.write('\r\n'.encode())

def process(line):
    for i in range(len(line)):
        if line[i] != '\n':
            if line[i] == 'P' and line[i+1] == 'P' and line[i+2] == ' ':
                print("+++++++++++++++++++")
                print("DECODED: ")
                print(line[i::-1])
                print("+++++++++++++++++++")

def update_text():
    try:
        if ser.in_waiting > 0:
            #process(ser.readline())
            end_line = b'\r' + b'\n'
            #received_data = ser.read_until(expected=b'\n')
            #print(ser.read_until(expected=b'\n'))
            received_data = ser.readline().decode('utf-8')
            print(f"RAW: {received_data}")
            #print(f"BYTES: {bytes(received_data, 'utf-8')}")
            print("--------------------------------------------")
            match = re.match(r'([A-Z]+) (\d+)', received_data)
            '''
            valor_x = cadena.split(" ")[1].strip()
            print(f"RAW: {valor_x}")
            print(f"BYTES: {bytes(valor_x, 'utf-8')}")
            tipo = cadena.split(" ")[0].strip()
            if tipo == "HU":
                hum_label.configure(text=f"Humidity: {((((float(valor_x) / 1024.0) * 5.0) - 0.826) / 0.0315):.1f}%")
            elif tipo == "TE":
                temp_label.configure(text=f"Temperature: {(((float(valor_x) / 1024.0) * 5.0) / 0.01):.1f}ºC")
            elif tipo == "PP":
                if valor_x.startswith("WAR"):
                    co2_label.configure(text=f"CO2: NO DISPONIBLE", text_color='yellow')
                elif valor_x.startswith("BUS"):
                    co2_label.configure(text=f"CO2: BUSY", text_color='red')
                elif valor_x.startswith("ERR"):
                    co2_label.configure(text=f"CO2: ERROR", text_color='red')
                elif valor_x.startswith("UNK"):
                    co2_label.configure(text=f"CO2: UNKOWN", text_color='red')
                else:
                    co2_label.configure(text=f"CO2: {valor_x} ppm")
            elif tipo == "LU":
                lux_label.configure(text=f"Lux: {valor_x} lx")
            elif tipo == "NO":
                if 0 <= int(valor_x) <= 400:
                    noise_label.configure(text=f"Ruido bajo", text_color='green')
                elif 400 < int(valor_x) <= 900:
                    noise_label.configure(text=f"Ruido intermedio", text_color='yellow')
                elif int(valor_x) > 900:
                    noise_label.configure(text=f"Ruido alto", text_color='red')
                else:
                    pass
            else:  # Maybe here load config on the GUI
                pass
            '''
            if received_data.startswith("WAR"):
                co2_label.configure(text=f"CO2: NO DISPONIBLE", text_color='yellow')
            elif received_data.startswith("BUS"):
                co2_label.configure(text=f"CO2: BUSY", text_color='red')
            elif received_data.startswith("ERR"):
                co2_label.configure(text=f"CO2: ERROR", text_color='red')
            elif received_data.startswith("UNK"):
                co2_label.configure(text=f"CO2: UNKOWN", text_color='red')
            else:  # Maybe here load config on the GUI
                pass
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

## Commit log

2023-11-23 Added main blocks from HLD + SPI + UASRT config
2023-12-12 Added UART receive
2023-12-13 Implemented I2C protocol. Added CO2 sensor functionality
2023-12-13 Added 2 I2C missing functions
2023-12-13 Added light sensor functionality
2023-12-15 Added LED SPI control
2023-12-15 Added PWM control
2023-12-17 UART flag down by sw
2023-12-19 Added I2C
